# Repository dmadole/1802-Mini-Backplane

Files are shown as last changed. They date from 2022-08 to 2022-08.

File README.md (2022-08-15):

# 1802-Mini-Backplane

This is a backplane for the [1802/Mini](https://github.com/dmadole/1802-Mini) system. It supports the following features:

* Seven slots using 1x39 single-row header sockets
* Power, reset, and, and input pushbuttons
* Power input via mini-USB or 2.1mm barrel jack
* USB pass-through header, can also be used for power
* Boards can be coupled end-to-end to make larger backplanes
* PCB can also be assembled as a slot extender card
* Optional pull-up resistors for TPA, TPB, and CLOCK

Gerber files for the PCBs and PDF schematics can be found in [Releases](https://github.com/dmadole/1802-Mini-Backplane/releases).

BOMS and any applicable errata or other notes can be found in [notes](https://github.com/dmadole/1802-Mini-Backplane/tree/main/notes).

For availability of kits and bare PCBs please see http://madole.net/1802/mini/kits

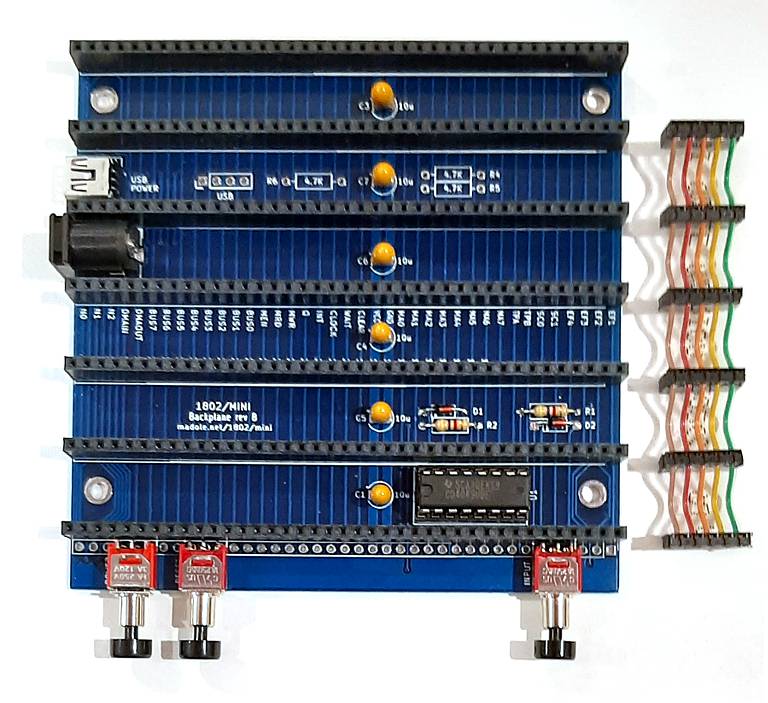
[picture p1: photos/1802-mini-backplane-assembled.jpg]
1802/Mini Backplane Front

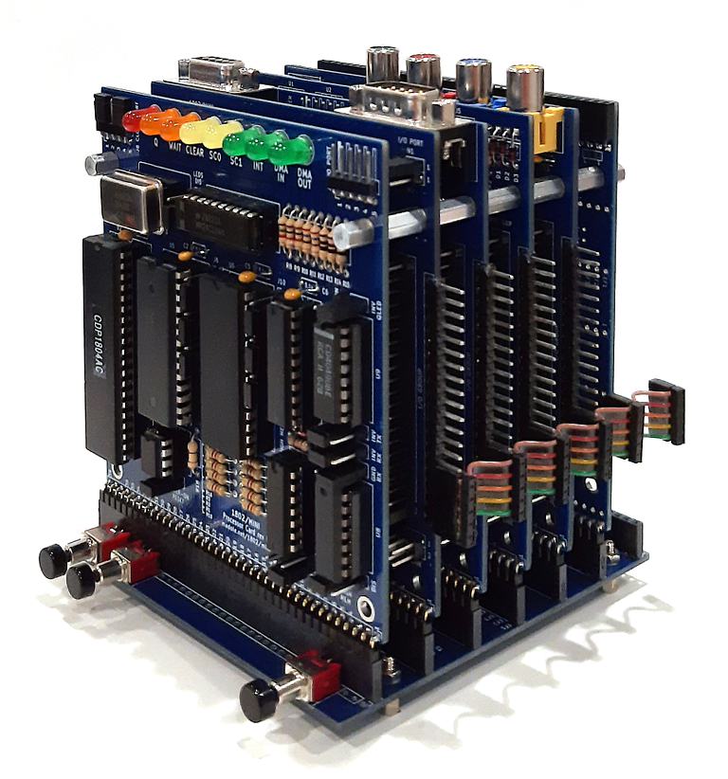
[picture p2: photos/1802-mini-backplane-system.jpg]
1802/Mini Backplane System

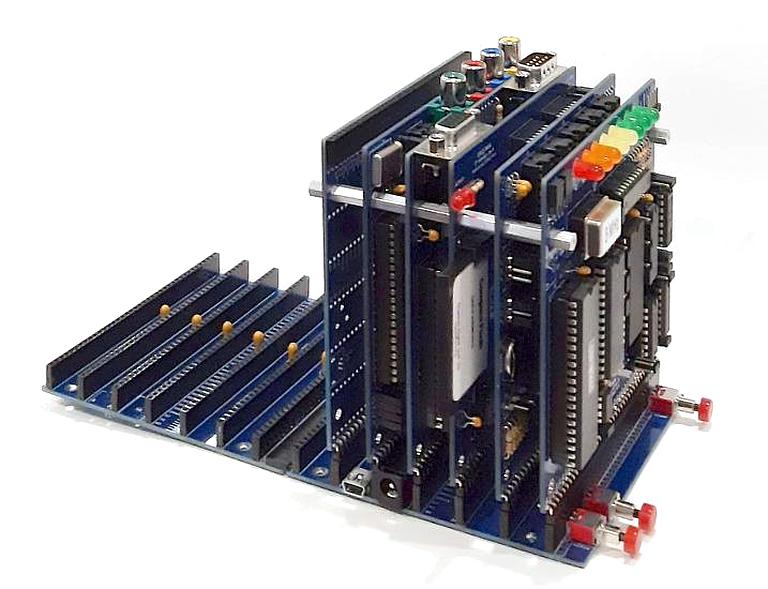
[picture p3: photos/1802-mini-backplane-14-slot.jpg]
1802/Mini Backplane 14 Slots


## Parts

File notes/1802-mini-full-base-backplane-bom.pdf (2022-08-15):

Note: Part numbers, manufacturers, and vendors are typical of what is supplied. Substitutions may be made based on availability at time of ordering.

### BACKPLANE

Qty | Description | Manufacturer Manufacturer # | Vendor | Vendor #

Integrated Circuits
1 | CD4049 | U1 | TI | CD4049UBE | Digikey | 296-2055-5-ND

Discrete Components
5 | Resistor 1/4 watt 4.7K | R1-6 | Stackpole | CF14JT4K70 | Digikey | CF14JT4K70CT-ND
2 | Diode 1N4148 | D1-2 | ON Semi | 1N4148 | Digikey | 1N4148FS-ND
6 | Tantalum capacitor 10uF radial 0.1" | C1-6 | AVX | TAP106K010SCS | Digikey | 478-1838-ND

Interconnect and Mechanical
1 | Straight header 4 pins 0.1" | | Sullins | PREC003SAAN-RC | Digikey | S1012EC-03-ND
1 | Mini-USB receptable AB | | Molex | 565790519 | Digikey | WM17121-ND
1 | 2.1mm barrel jack | | CUI | PJ-102AH | Digikey | CP-102AH-ND

Input Switchews
1 | SPDT push button 0.1" spacing | | E-Switch | 800CSP1B6M6QE | Mouser | 612-800CSP1B6M6QE
2 | SPDT push button 0.1" spacing | | E-Switch | 800SP8B7M6QE | Mouser | 612-800-B761
3 | Switch cap, black | | E-Switch | 800C2BLKCAP | Mouser | 612-800C2BLKCAP

Integrated Circuit Sockets
1 | DIP socket 16 pin 0.3" | U1 | On Shore | ED16DT | Digikey | ED3046-5-ND

Circuit Board and Expansion
1 | Circuit Board | | Madole | | JLCPCB
7 | Socket 39 pin 0.1" short tail | | Samtec | SSQ-139-01-T-S | Digikey | SAM1184-39-ND

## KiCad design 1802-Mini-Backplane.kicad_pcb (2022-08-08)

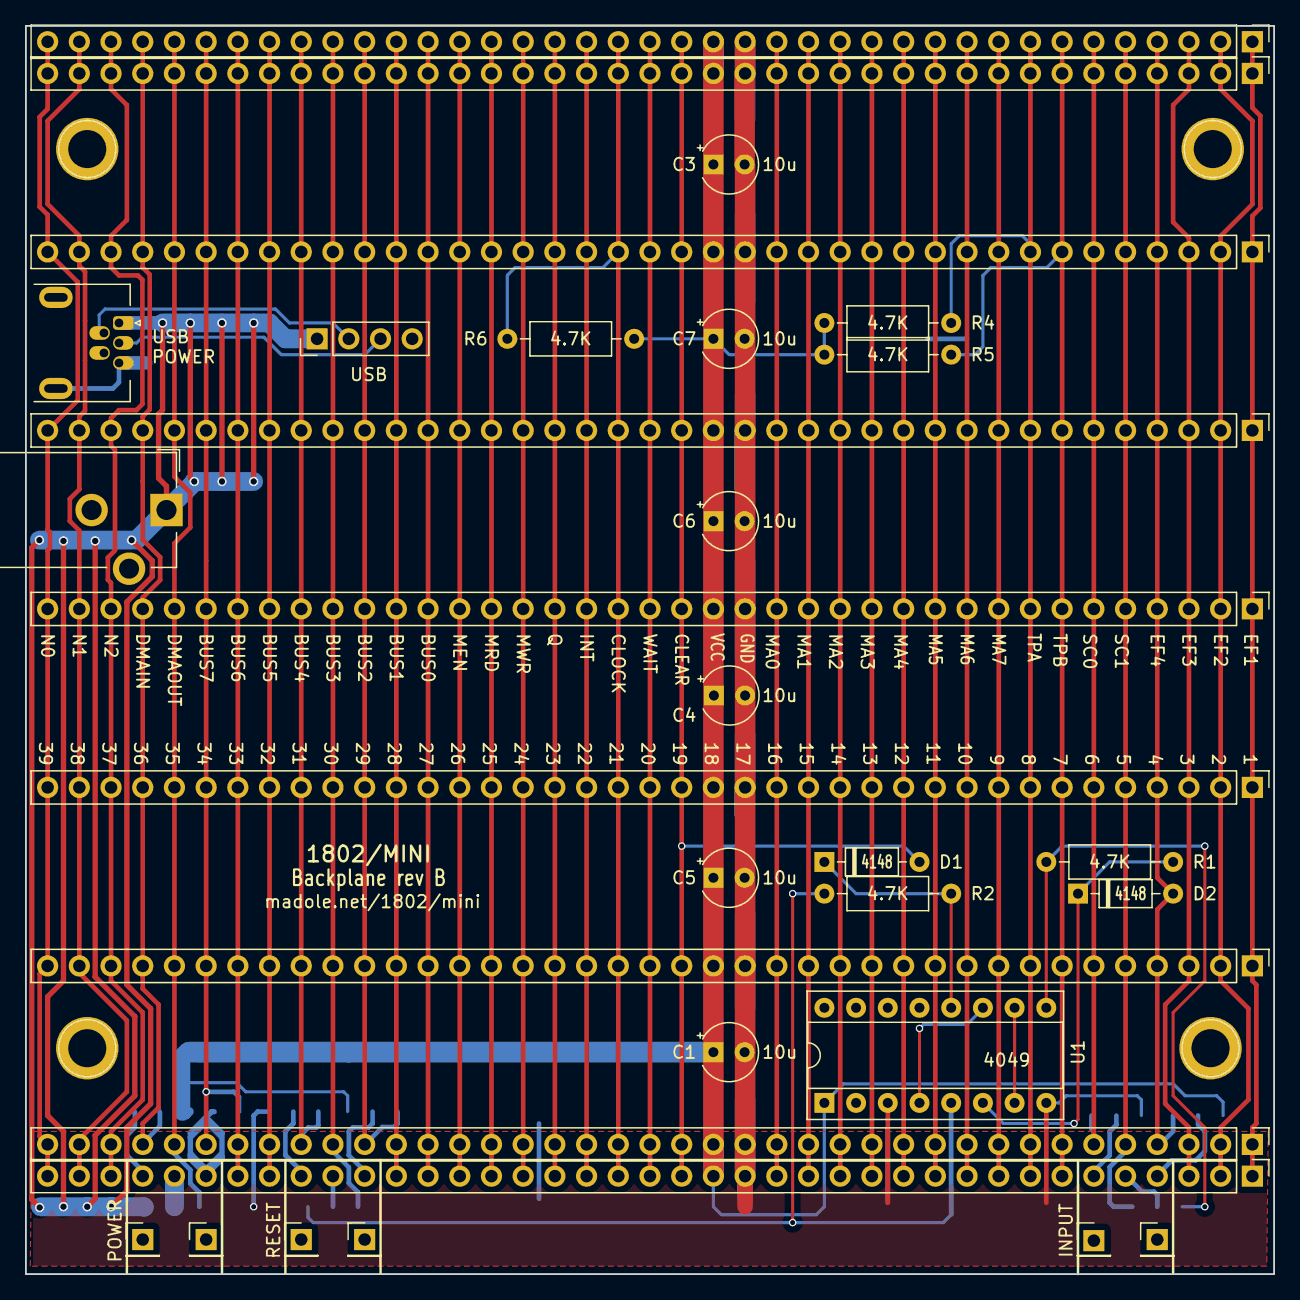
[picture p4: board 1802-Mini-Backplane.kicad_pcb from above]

Board: 2 copper layers, 100.0 x 100.0 mm, 45 parts (0 on the bottom side), 57 nets.

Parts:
C1, C3, C4, C5, C6, C7: 10uF; CP_Radial_Tantal_D4.5mm_P2.50mm
D1, D2: 1N4148; D_DO-35_SOD27_P7.62mm_Horizontal
J1: Barrel_Jack_Switch; BarrelJack_CUI_PJ-102AH_Horizontal
J2, J3, J4, J5, J6, J7, J8, J14, J15: Expansion; PinHeader_1x39_P2.54mm_Vertical
J9, J10, J11, J12: Mount; 1pin
J13: 56579-0519; USB_Mini-AB_Molex_56579_0519
J16, J17, J18, J19, J20, J21: Mount; PinHeader_1x01_P2.54mm_Vertical
J22: Conn_01x04; PinHeader_1x04_P2.54mm_Vertical
JP1, JP2, JP3, JP4, JP5, JP6, JP7, JP8, JP9: Jumper_3_Open; SolderJumper-3_P2.0mm_Open_TrianglePad1.0x1.5mm_NumberLabels
R1, R2, R4, R5, R6: 4.7K; R_Axial_DIN0207_L6.3mm_D2.5mm_P10.16mm_Horizontal
U1: 4049; DIP-16_W7.62mm_Socket

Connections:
/BUS0: J2.27, J3.27, J4.27, J5.27, J6.27, J7.27, J8.27, J14.27, J15.27
/BUS1: J2.28, J3.28, J4.28, J5.28, J6.28, J7.28, J8.28, J14.28, J15.28
/BUS2: J2.29, J3.29, J4.29, J5.29, J6.29, J7.29, J8.29, J14.29, JP4.3
/BUS3: J2.30, J3.30, J4.30, J5.30, J6.30, J7.30, J8.30, J14.30, JP5.3
/BUS4: J2.31, J3.31, J4.31, J5.31, J6.31, J7.31, J8.31, J14.31, JP6.3
/BUS5: J2.32, J3.32, J4.32, J5.32, J6.32, J7.32, J8.32, J14.32, J15.32
/BUS6: J2.33, J3.33, J4.33, J5.33, J6.33, J7.33, J8.33, J14.33, J15.33
/BUS7: J2.34, J3.34, J4.34, J5.34, J6.34, J7.34, J8.34, J14.34, JP7.3
/MA0: J2.16, J3.16, J4.16, J5.16, J6.16, J7.16, J8.16, J14.16, J15.16
/MA1: J2.15, J3.15, J4.15, J5.15, J6.15, J7.15, J8.15, J14.15, J15.15
/MA2: J2.14, J3.14, J4.14, J5.14, J6.14, J7.14, J8.14, J14.14, J15.14
/MA3: J2.13, J3.13, J4.13, J5.13, J6.13, J7.13, J8.13, J14.13, J15.13
/MA4: J2.12, J3.12, J4.12, J5.12, J6.12, J7.12, J8.12, J14.12, J15.12
/MA5: J2.11, J3.11, J4.11, J5.11, J6.11, J7.11, J8.11, J14.11, J15.11
/MA6: J2.10, J3.10, J4.10, J5.10, J6.10, J7.10, J8.10, J14.10, J15.10
/MA7: J2.9, J3.9, J4.9, J5.9, J6.9, J7.9, J8.9, J14.9, J15.9
CLOCK: J2.21, J3.21, J4.21, J5.21, J6.21, J7.21, J8.21, J14.21, J15.21, R6.2
DMA_IN: J2.36, J3.36, J4.36, J5.36, J6.36, J7.36, J8.36, J14.36, JP9.3
DMA_OUT: J2.35, J3.35, J4.35, J5.35, J6.35, J7.35, J8.35, J14.35, JP8.3
EF1: J2.1, J3.1, J4.1, J5.1, J6.1, J7.1, J8.1, J14.1, J15.1
EF2: J2.2, J3.2, J4.2, J5.2, J6.2, J7.2, J8.2, J14.2, J15.2
EF3: J2.3, J3.3, J4.3, J5.3, J6.3, J7.3, J8.3, J14.3, J15.3
EF4: D2.2, J2.4, J3.4, J4.4, J5.4, J6.4, J7.4, J8.4, J14.4, JP1.3
GND: C1.2, C3.2, C4.2, C5.2, C6.2, C7.2, J1.2, J2.17, J3.17, J4.17, J5.17, J6.17, J7.17, J8.17, J13.5, J13.6, J14.17, J15.17, J22.4, JP3.1, JP6.1, U1.3, U1.8, U1.14
INTERRUPT: J2.22, J3.22, J4.22, J5.22, J6.22, J7.22, J8.22, J14.22, J15.22
MEN: J2.26, J3.26, J4.26, J5.26, J6.26, J7.26, J8.26, J14.26, J15.26
MRD: J2.25, J3.25, J4.25, J5.25, J6.25, J7.25, J8.25, J14.25, J15.25
MWR: J2.24, J3.24, J4.24, J5.24, J6.24, J7.24, J8.24, J14.24, J15.24
N0: J2.39, J3.39, J4.39, J5.39, J6.39, J7.39, J8.39, J14.39, J15.39
N1: J2.38, J3.38, J4.38, J5.38, J6.38, J7.38, J8.38, J14.38, J15.38
N2: J2.37, J3.37, J4.37, J5.37, J6.37, J7.37, J8.37, J14.37, J15.37
unnamed: D1.1, R2.1, U1.12
unnamed: D2.1, R1.1, U1.6
unnamed: J1.1, J13.1, J22.1, JP8.1
unnamed: J13.2, J22.2
unnamed: J13.3, J22.3
unnamed: J15.4, JP1.2
unnamed: J15.5, JP2.2
unnamed: J15.6, JP3.2
unnamed: J15.29, JP4.2
unnamed: J15.30, JP5.2
unnamed: J15.31, JP6.2
unnamed: J15.34, JP7.2
unnamed: J15.35, JP8.2
unnamed: J15.36, JP9.2
unnamed: JP2.1, R1.2, U1.9
unnamed: JP5.1, R2.2, U1.5
unnamed: U1.7, U1.10
unnamed: U1.4, U1.11
Q: J2.23, J3.23, J4.23, J5.23, J6.23, J7.23, J8.23, J14.23, J15.23
SC0: J2.6, J3.6, J4.6, J5.6, J6.6, J7.6, J8.6, J14.6, JP3.3
SC1: J2.5, J3.5, J4.5, J5.5, J6.5, J7.5, J8.5, J14.5, JP2.3
TPA: J2.8, J3.8, J4.8, J5.8, J6.8, J7.8, J8.8, J14.8, J15.8, R4.2
TPB: J2.7, J3.7, J4.7, J5.7, J6.7, J7.7, J8.7, J14.7, J15.7, R5.2
VCC: C1.1, C3.1, C4.1, C5.1, C6.1, C7.1, J2.18, J3.18, J4.18, J5.18, J6.18, J7.18, J8.18, J14.18, J15.18, JP1.1, JP4.1, JP7.1, R4.1, R5.1, R6.1, U1.1
~CLEAR: D1.2, J2.19, J3.19, J4.19, J5.19, J6.19, J7.19, J8.19, J14.19, J15.19
~WAIT: J2.20, J3.20, J4.20, J5.20, J6.20, J7.20, J8.20, J14.20, J15.20

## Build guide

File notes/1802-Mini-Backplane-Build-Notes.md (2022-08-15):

# 1802/Mini Backplane Build Notes

## Input and Reset Switches

If you are using a front panel card, you may not want to install the RESET or INPUT switches, since you can do those same things with the front panel, but they can be installed if you want and will function alongside the front panel controls. If you don’t install those switches you can leave out the 4049, the diodes, and the resistors.

## Switch Identification

There are two kinds of switches, you can tell them apart because one will click when you press it, that’s the one for the power switch. You can not install the power switch too if you don’t want, but you need to jumper the pins where it would have gone.

## Jumper Bridges
For the switches to work, you need to bridge the nine sets of solder pads on the back of the board around the switch locations on the “1” side. If you are building a backplane expander to add another 7 slots, then you will instead jumper on the "3" side. For a slot extender, they should not be jumpered at all.

## As a Slot Extender

If you are building the PCB as a slot extender, you should install the connectors on what would normally be the solder side of the board, rather than the component side of the board. This will result in the correct location of the power traces on the board.

## Optional Pull-Up Resistors

The R4-R7 resistor positions are for optional pull-up resistors for overclocking experiments. I have found that at high clock rates, TPB rising edges become soft and a pull-up resistor can help give a little more headroom. These locations provide for pull-ups on TPA, TPB, and CLOCK, and are considered experimental and not needed for normal use.
